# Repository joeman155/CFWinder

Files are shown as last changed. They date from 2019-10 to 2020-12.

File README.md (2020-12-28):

# CFWinder
** This is my gift to others to help them. I am still available - for paid Professional Engineering advice, 
   if your endeavour is for Financial gain. Otherwise, kindly refer to me somewhere in your notes, if you are blogging **

!!! Wishing you the very besy of success in your proejct. !!!

** WARNING **
Unfortunately there are no instructions for getting this up and running....but can give a quick overview...to get you started.

** The software and hardware required **
This project used LinuxCNC to control stepper motors. This is just a specialised version of Linux
with LinuxCNC installed...that does all the HARD work of controlling stepper motors. You still need to 
do some hard work, just not as much.  (Who wants to re-invent the wheel?)

Go get some good Stepper motors from OMC.  https://www.omc-stepperonline.com/  ... good PSU..... well spec'd Drivers...
and follow already well described tutorials on hooking these up.

NOTE: With LinuxCNC I used an oldish PC with an old style Parallel Port. IT works REALLY well!

** Folders in this code **
NOTE: There are three branches. master...for tubes..... to for noseccones.....use the NG variant for NOSECones.

> linucnc folder - has some configurations for the setup I had....PURELY LinuxCNC
    just some configurations
	
> gcodeGenerator - PHP web application that you installed on the SAME machine as linuxcnc with Apache + PHP. 
    You go to a web page...enter in some values...and it generates the GCode to do the job.
    A lot of patience and time required to figure this out...but less time than it would be to start from scratch.  
	Alternatively, start your own app... and pull out bits you like from here...
	
> 3-D_Designs
    A collection of unverified designs of parts used in my project.
    Use them as a starting point if you wish.

** Key Design **
- Three Axis - absolutely necessary   (Axle, left-right and tilt of CF)
- Go for L-XXX belts (don't try XL, even though it theoretically should)
- Have a heavy sturdy, flat bench
- Vibrations are your enemy
- The idler needs to be very well designed - using bearings. Has to be well balanced
- Get your gears professionaly drilled on a lathe.  (Unbalanced parts are your enemy).
- 8020.net is a good place to get the elements of your design.
- With your Mandrel, Aluminum worked out the best...but you NEED TO PREPARE IT VERY CAREFULLY. It takes a LOT OF TIME...Painful, but it pays off.
  It needs to be VERY VERY smooth....and a suitable former (not too tight!!!! needs to be put on to Mandrel)
  Yes....you will need dry-Ice to remove it....
  YEs.... ask someone to help remove the CF tube....
  Yes.... you shouldn't wait any longer than necessary before removing CF tube...it shrinks and you need to reduce all risks of not being able to remove it.
  
Unfortunately there is a lot that needs to be learnt on the job. But don't be put off. It is incredibly rewarding.

Joe

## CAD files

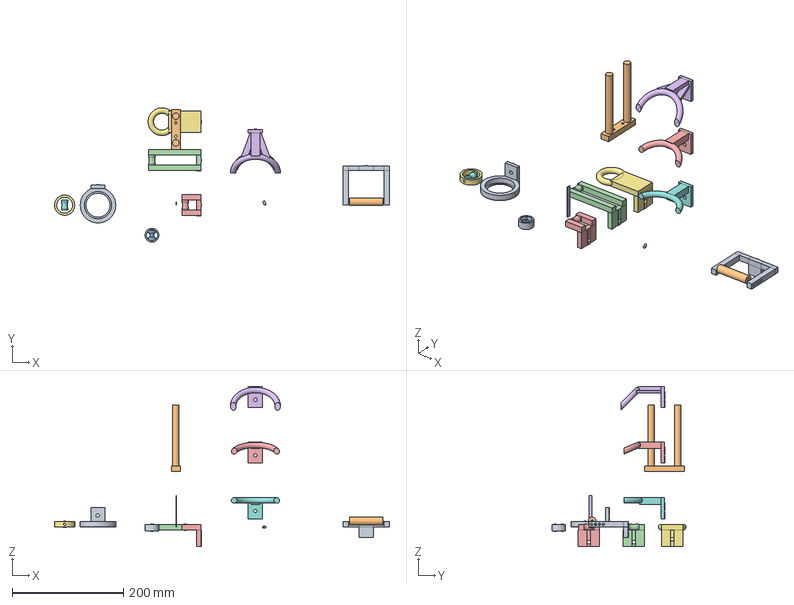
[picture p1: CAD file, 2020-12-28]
3-D_Designs/CFGuides.FCStd
602.2 x 241.5 x 288.0 mm
MidWayEyelet
Roller1
LEFT_RIGHT_GUIDE

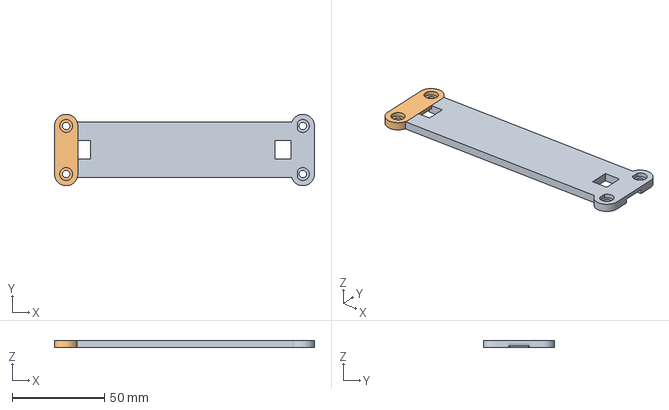
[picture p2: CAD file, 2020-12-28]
3-D_Designs/Balancer.FCStd
140.6 x 38.6 x 4.00 mm
ExtendedClamp
beltClamp

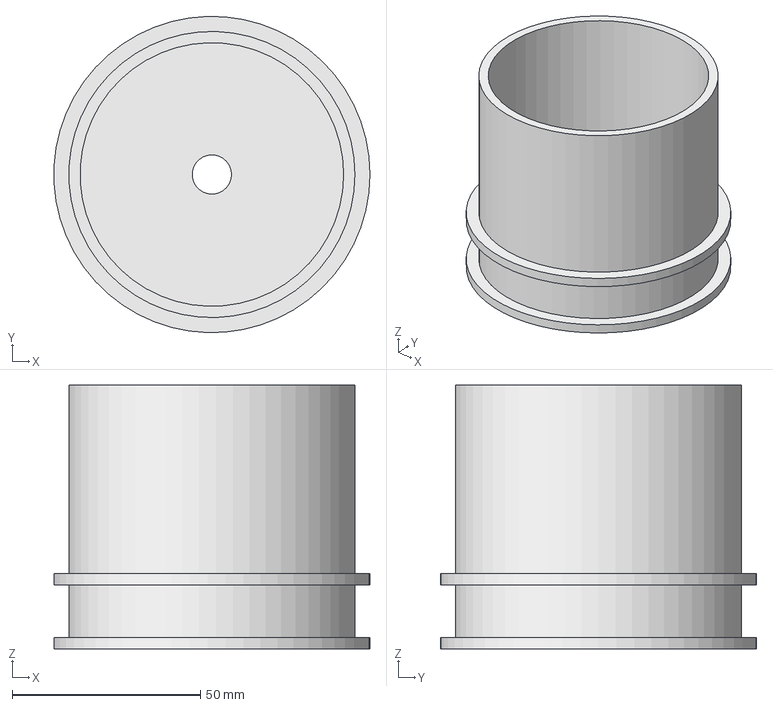
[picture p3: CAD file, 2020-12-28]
3-D_Designs/CarbonFiberRollHolder.FCStd
83.9 x 84.0 x 70.0 mm

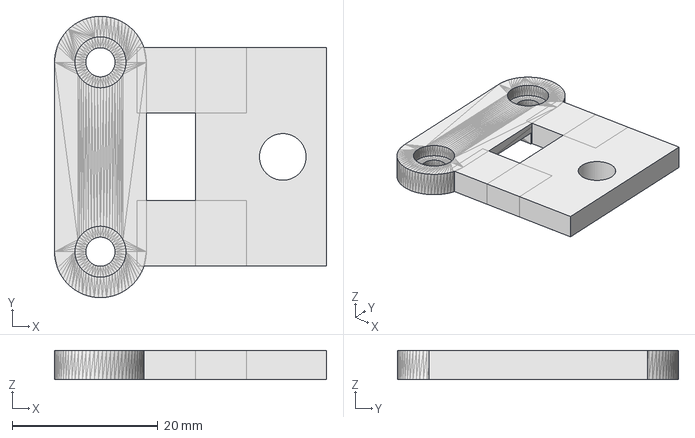
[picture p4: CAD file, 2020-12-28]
3-D_Designs/TopClampPart.FCStd
37.3 x 38.6 x 4.00 mm

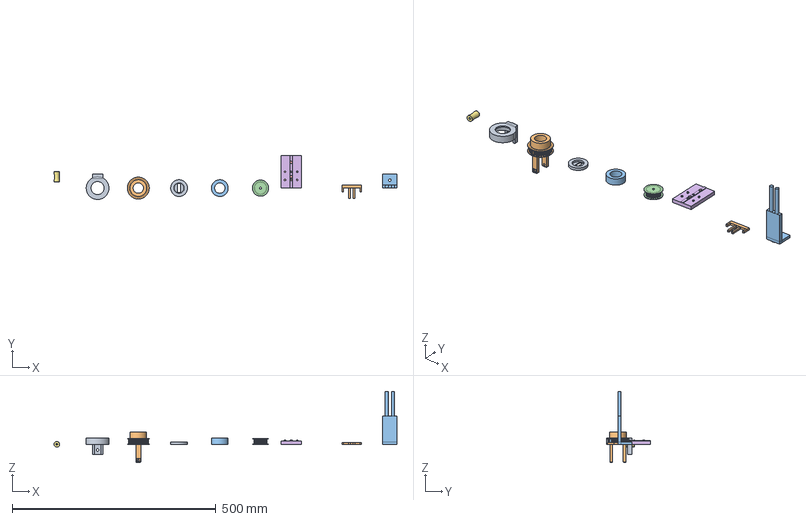
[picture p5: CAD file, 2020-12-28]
3-D_Designs/ThirdAxis.FCStd
842.0 x 108.0 x 175.0 mm
CF_Front_Dispenser

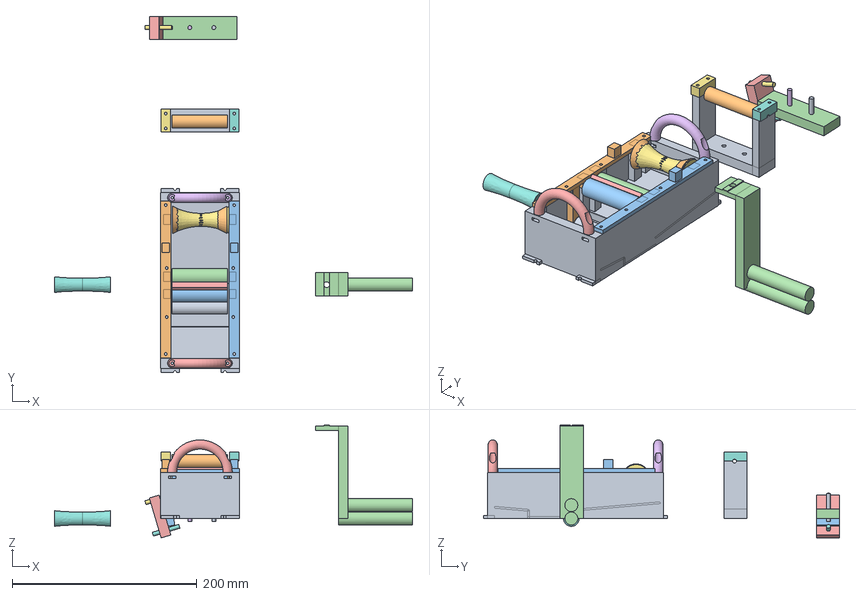
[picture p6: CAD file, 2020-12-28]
3-D_Designs/Epoxy_Tray.FCStd
387.5 x 385.0 x 122.0 mm
Roller1
ROLLER4
Roller2
Roller013
DRBlade
GlueRoller
CurvedEntryRoller
Roller011
FrontHardLimit
BackHardLimit
Roller015
BASE001
Pillar_Front_Right009
BASE
boltHole036
boltHole038
boltHole037
boltHole035

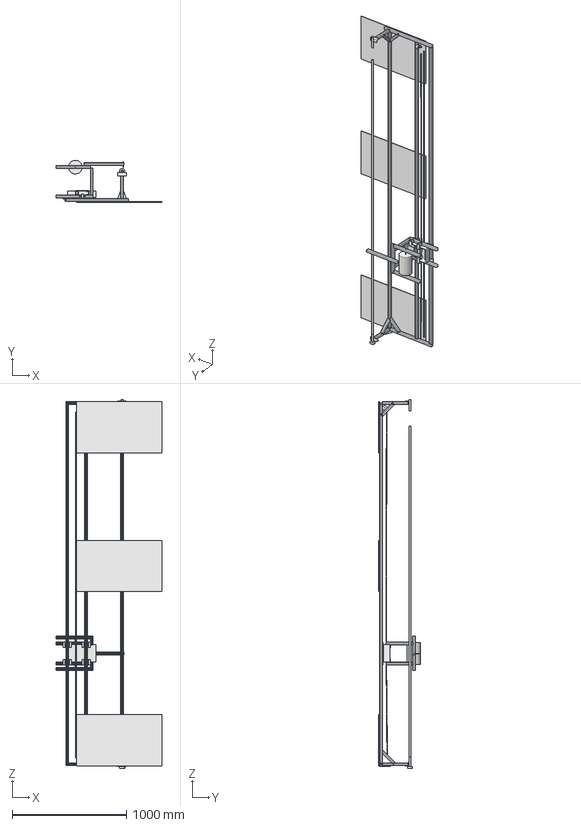
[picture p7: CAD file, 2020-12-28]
3-D_Designs/Starting_Idea_Inspiration.FCStd
926.6 x 370.6 x 3232.0 mm
longbeam001
longbeam002
depth001
depth002
longbeam003
fortyfive001
fortyfive002
Post001
DriveSpindle
fortyfive005
LinearDrivePulley002
Pillow_Bearing_Mount001
Post002
DrivenSpindle
fortyfive006
Pillow_Bearing_Mount002
GludeContainer
RW
LW
Epoxy_Tray_Riser001
Epoxy_Tray_Riser003
Epoxy_Tray_Riser005
Epoxy_Tray_Riser007
Special_Roller
BottomRoller
FrontTopRoller
BackTopRoller
CFGuide_HBeam002
Eyelet
LinearBearing001
LinearBearing002
LinearBearing003
LinearBearing004
Platform001
Belt001
Belt002
tray_Riser001
tray_Riser002
CF_Spindle_mount_base001
CF_Mount_Post001
CFGuidePost001
CFGuidePost002
CF_Mount_Post002
Belt003
IdlerPulley001
IdlerAxle
MotorAxle003
LinearDrivePulley004
LeftTableTop
RightTableTop001
LeftTableTop001
cf_Roll
Bobbin_Spindle
Smallmandrel

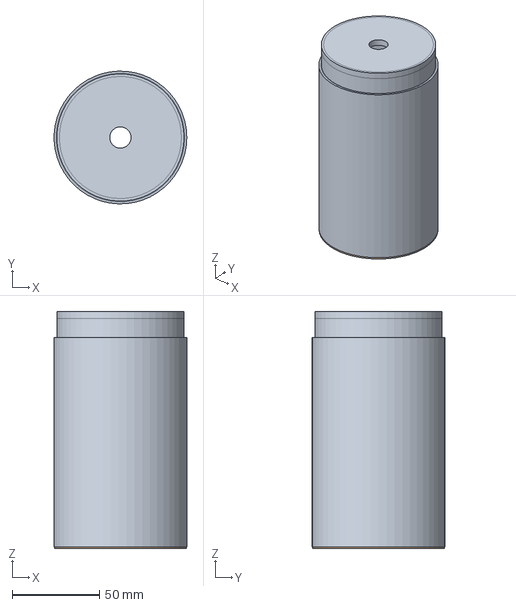
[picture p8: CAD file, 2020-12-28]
3-D_Designs/NoseCone_Mandrel.FCStd
76.1 x 76.2 x 136.0 mm
Core_part
Cap

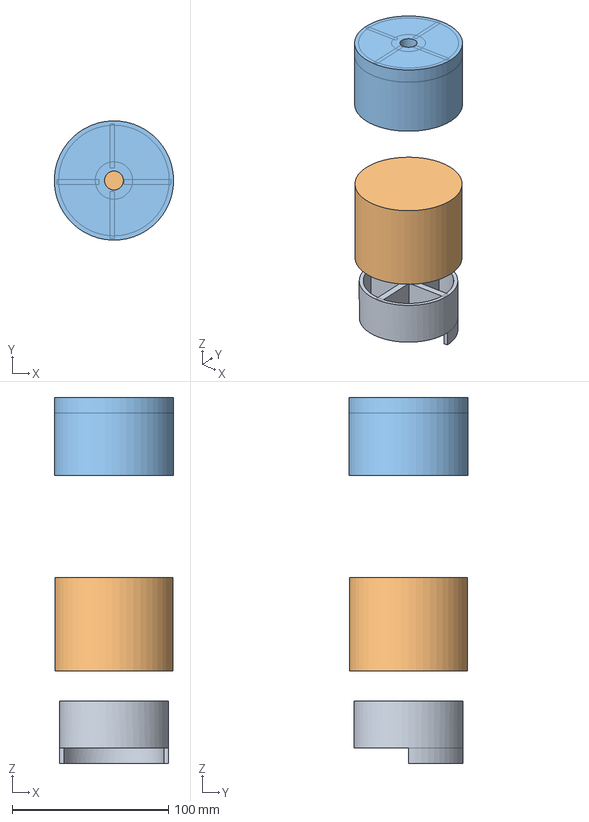
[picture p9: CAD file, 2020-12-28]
3-D_Designs/Mandrel_Shaft_Connect-for-CF-Tube.FCStd
76.2 x 76.3 x 234.0 mm
Mandrel_INSERT
Plastic_Mandrel
CF_Adapter_for_AF

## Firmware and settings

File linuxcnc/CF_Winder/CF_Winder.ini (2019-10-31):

# Generated by stepconf 1.1 at Mon Feb 25 21:22:01 2019
# If you make changes to this file, they will be
# overwritten when you run stepconf again

[EMC]
MACHINE = CF_Winder
DEBUG = 0

[DISPLAY]
DISPLAY = axis
EDITOR = gedit
POSITION_OFFSET = RELATIVE
POSITION_FEEDBACK = ACTUAL
ARCDIVISION = 64
GRIDS = 10mm 20mm 50mm 100mm 1in 2in 5in 10in
MAX_FEED_OVERRIDE = 1.2
MIN_SPINDLE_OVERRIDE = 0.5
MAX_SPINDLE_OVERRIDE = 1.2
DEFAULT_LINEAR_VELOCITY = 40.00
MIN_LINEAR_VELOCITY = 0
MAX_LINEAR_VELOCITY = 360.00
DEFAULT_ANGULAR_VELOCITY = 36.00
MIN_ANGULAR_VELOCITY = 0
MAX_ANGULAR_VELOCITY = 360.00
INTRO_GRAPHIC = linuxcnc.gif
INTRO_TIME = 5
PROGRAM_PREFIX = /home/user/linuxcnc/nc_files
INCREMENTS = 5mm 1mm .5mm .1mm .05mm .01mm .005mm
TOLERANCE_MM = 0.1

[FILTER]
PROGRAM_EXTENSION = .png,.gif,.jpg Greyscale Depth Image
PROGRAM_EXTENSION = .py Python Script
png = image-to-gcode
gif = image-to-gcode
jpg = image-to-gcode
py = python

[TASK]
TASK = milltask
CYCLE_TIME = 0.010

[RS274NGC]
PARAMETER_FILE = linuxcnc.var

[EMCMOT]
EMCMOT = motmod
COMM_TIMEOUT = 1.0
COMM_WAIT = 0.010
BASE_PERIOD = 100000
# BASE_PERIOD = 45028
SERVO_PERIOD = 1000000

[HAL]
HALFILE = CF_Winder.hal
HALFILE = custom.hal
POSTGUI_HALFILE = custom_postgui.hal

[TRAJ]
AXES = 4
COORDINATES = X Y Z A
LINEAR_UNITS = mm
ANGULAR_UNITS = degree
CYCLE_TIME = 0.010
DEFAULT_VELOCITY = 36.00
MAX_VELOCITY = 200.00

[EMCIO]
EMCIO = io
CYCLE_TIME = 0.100
TOOL_TABLE = tool.tbl

[AXIS_0]
TYPE = LINEAR
HOME = 0.0
MAX_VELOCITY = 200.0
MAX_ACCELERATION = 1200.0
STEPGEN_MAXACCEL = 1800.0
SCALE = 13.17
# SCALE Steps per unit
# microstep = 8
# steps per degree = 1.8
# 360 degrees per rev
# Outer Diameter = 36.5, So Pitch Diameter is about 37mm. So ...
# 1 revolution = circumference = 3.1415 *37 = 116.24
# 1 rev = 20 teeth - each tooth = 0.2" = 5.08" i.e. 1 rev = 116.24mm
# SCALE = (8/1.8) * (360/1) * (1/101.6) = 13.76
FERROR = 1
MIN_FERROR = .0025
MIN_LIMIT = -0.001
MAX_LIMIT = 2650.0
HOME_OFFSET = -10.000000
HOME_SEARCH_VEL = 35.00000
HOME_LATCH_VEL = -3.00000
HOME_IGNORE_LIMITS = YES
# HOME_SEARCH_VEL = 0
# HOME_LATCH_VEL = 0

[AXIS_1]
TYPE = ANGULAR
HOME = 0.0
MAX_VELOCITY = 200.0
MAX_ACCELERATION = 1000.0
STEPGEN_MAXACCEL = 1300
# SCALE = 3.96946564885
# SCALE = 5.77778
# SCALE = 5.78563
# SCALE = 5.779594
# SCALE = 5.87617
# SCALE = 5.8516
#
# I ended up realizing the fudge factors were wrong.
# Slowed the speed right down...and 5.78 is pretty close to it.
# SCALE = 5.78
# SCALE = 8.68877386155 # The theoretically correct value
# SCALE = 8.69
# SCALE = 8.7614
# THEN MULTIPLE by 0.99958227
# SCALE = 8.75774
# That meant it was short in the 4th test!!
# SCALE = 8.7614
# increasing microsteps to 32
# SCALE = 35.0456
# SCALE = 35.0456
# SCALE = 34.995
# SCALE = 35.0461754
# Times by 0.9998604
# SCALE = 35.0414806
# Times 0.99997016
# SCALE = 35.040435
# Times by 0.99997016 again
# SCALE = 35.0393894
# Times by 0.99069332
# SCALE = 34.71328903
# Times by 1.001480608
#SCALE = 34.7646858

# DECIDED TO REDUCE to 16 micro steps (from 32)
SCALE = 17.38


# SCALE Steps per degree
# microstep = 8
# steps per degree = 1.8
# Gear scale = 26/20 = 13/10 = 1.3
# 1 degree ....of travel for 38.1mm radius...= tangential distance of 0.66497044501mm
# (3.1415/180) * 38.1 = 0.66497044501mm
# Multipler = 1.00835459   # Experimentally found to ensure 360 degrees
#
# SCALE = (8/1.8) * (26/20) * (180 /(3.141592*38.1)) * 1.00835459= 8.7614
FERROR = 1
MIN_FERROR = .25
MIN_LIMIT = -999999999
MAX_LIMIT = 999999999
HOME_OFFSET = 0.0
HOME_SEARCH_VEL = 0
HOME_LATCH_VEL = 0

[AXIS_2]
TYPE = ANGULAR
HOME = 0.0
STEPGEN_MAXACCEL = 1300
MAX_VELOCITY = 200.0
MAX_ACCELERATION = 750.0
STEPGEN_MAXACCEL = 937.5
# SCALE = (32/1.8) * (30/20) = 26.67
# SCALE = 26.67
# SCALE = 29
SCALE = 28.03
FERROR = 1
MIN_FERROR = .25
MIN_LIMIT = -180.0
MAX_LIMIT = 180
HOME_OFFSET = 0.0
HOME_SEARCH_VEL = 0
HOME_LATCH_VEL = 0

[AXIS_3]
TYPE = ANGULAR
HOME = 0.0
MAX_VELOCITY = 1 
MAX_ACCELERATION = 20 
STEPGEN_MAXACCEL = 26
STEPGEN_MAXVEL = 2.6
SCALE = 2064
#
# I did test at 6 RPM (not fast) for 60 seconds. i.e. 10 secs per ref
# I expected it to finish where it started....for the theoretical value 
# of 2080 it did not...it overshot by about 11mm. So I determined that we needed
# closer to 2064 steps to ensure that it would not overshoot, This was about
# right.
#

# SCALE Steps per rev
# microstep = 8
# steps per degree = 1.8
# 360 degrees per rev
# 1 rev = 20 teeth - each tooth = 0.2" = 5.08" i.e. 1 rev = 101.6mm
# Gear scale = 26/20 = 13/10 = 1.3
# SCALE = (8/1.8) * (360/1) * (26/20) = 2080

FERROR = 25
MIN_FERROR = 1
MIN_LIMIT = -9999.0
MAX_LIMIT = 9999.0
HOME_OFFSET = 0.0
HOME_SEARCH_VEL = 0
HOME_LATCH_VEL = 0

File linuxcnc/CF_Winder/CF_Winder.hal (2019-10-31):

# Generated by stepconf 1.1 at Mon Feb 25 21:22:01 2019
# If you make changes to this file, they will be
# overwritten when you run stepconf again
loadrt trivkins
loadrt [EMCMOT]EMCMOT base_period_nsec=[EMCMOT]BASE_PERIOD servo_period_nsec=[EMCMOT]SERVO_PERIOD num_joints=[TRAJ]AXES
loadrt hal_parport cfg="0 out"
setp parport.0.reset-time 5000
loadrt stepgen step_type=0,0,0,0 ctrl_type=p,p,p,v
loadrt scale
loadrt orient
loadrt pid names=orient-pid

addf scale.0 servo-thread
setp scale.0.gain 0.0166667
addf parport.0.read base-thread
addf stepgen.make-pulses base-thread
addf parport.0.write base-thread
addf parport.0.reset base-thread

addf stepgen.capture-position servo-thread
addf motion-command-handler servo-thread
addf motion-controller servo-thread
addf stepgen.update-freq servo-thread
net spindle-cmd-rpm <= motion.spindle-speed-out => scale.0.in
net spindle-cmd-rpm-abs <= motion.spindle-speed-out-abs
net spindle-at-speed    => motion.spindle-at-speed


net estop-out       => parport.0.pin-01-out
net xstep           => parport.0.pin-02-out
setp parport.0.pin-02-out-reset 1
setp parport.0.pin-03-out-invert 1
net xdir            => parport.0.pin-03-out
net ystep           => parport.0.pin-04-out
net ydir            => parport.0.pin-05-out
net zstep           => parport.0.pin-06-out
net zdir            => parport.0.pin-07-out
net xenable         => parport.0.pin-14-out
net home-x          <= parport.0.pin-15-in
net min-home-x          <= parport.0.pin-15-in-not
net max-x           <= parport.0.pin-11-in-not


setp stepgen.0.position-scale [AXIS_0]SCALE
setp stepgen.0.steplen 1
setp stepgen.0.stepspace 0
setp stepgen.0.dirhold 33509
setp stepgen.0.dirsetup 33509
setp stepgen.0.maxaccel [AXIS_0]STEPGEN_MAXACCEL
net xpos-cmd axis.0.motor-pos-cmd => stepgen.0.position-cmd
net xpos-fb stepgen.0.position-fb => axis.0.motor-pos-fb
net xstep <= stepgen.0.step
net xdir <= stepgen.0.dir 
net xenable axis.0.amp-enable-out => stepgen.0.enable
net home-x => axis.0.home-sw-in
net max-x => axis.0.pos-lim-sw-in
net min-home-x => axis.0.neg-lim-sw-in


setp stepgen.1.position-scale [AXIS_1]SCALE
setp stepgen.1.steplen 1
setp stepgen.1.stepspace 0
setp stepgen.1.dirhold 33509
setp stepgen.1.dirsetup 33509
setp stepgen.1.maxaccel [AXIS_1]STEPGEN_MAXACCEL
setp stepgen.1.maxvel [AXIS_1]MAX_VELOCITY
net ypos-cmd axis.1.motor-pos-cmd => stepgen.1.position-cmd
net ypos-fb stepgen.1.position-fb => axis.1.motor-pos-fb
net ystep <= stepgen.1.step
net ydir <= stepgen.1.dir
net yenable axis.1.amp-enable-out => stepgen.1.enable


setp stepgen.2.position-scale [AXIS_2]SCALE
setp stepgen.2.steplen 1
setp stepgen.2.stepspace 0
setp stepgen.2.dirhold 33509
setp stepgen.2.dirsetup 33509
setp stepgen.2.maxaccel [AXIS_2]STEPGEN_MAXACCEL
net zpos-cmd axis.2.motor-pos-cmd => stepgen.2.position-cmd
net zpos-fb stepgen.2.position-fb => axis.2.motor-pos-fb
net zstep <= stepgen.2.step
net zdir <= stepgen.2.dir
net zenable axis.2.amp-enable-out => stepgen.2.enable

setp stepgen.3.position-scale [AXIS_3]SCALE
setp stepgen.3.steplen 1
setp stepgen.3.stepspace 0
setp stepgen.3.dirhold 33509
setp stepgen.3.dirsetup 33509
setp stepgen.3.maxaccel [AXIS_3]STEPGEN_MAXACCEL
setp stepgen.3.maxvel [AXIS_3]MAX_VELOCITY
# net spindle-cmd-rps <= scale.0.out => stepgen.3.velocity-cmd
# net ystep <= stepgen.3.step
# net ydir <= stepgen.3.dir
# net spindle-on motion.spindle-on => stepgen.3.enable

net estop-out <= iocontrol.0.user-enable-out
net estop-out => iocontrol.0.emc-enable-in

loadusr -W hal_manualtoolchange
net tool-change iocontrol.0.tool-change => hal_manualtoolchange.change
net tool-changed iocontrol.0.tool-changed <= hal_manualtoolchange.changed
net tool-number iocontrol.0.tool-prep-number => hal_manualtoolchange.number
net tool-prepare-loopback iocontrol.0.tool-prepare => iocontrol.0.tool-prepared

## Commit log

2019-03-12 * Starting to add project files.
    [CF_Winder.hal, CF_Winder.ini, custom.hal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]
2019-03-15 * Re org CF_Winder dir * Removing some unrequired parameters from Gcode generator * Moving away from _y to _s (s for spindle) * Fixed up calcs for second transition - was setting wrong Center points.
    [CF_Winder.hal, CF_Winder.ini, custom.hal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]
2019-03-17 * Updated linuxcnc config to allow use of Y axis with mm. * Updating gcode generator code to allow creation of files with curved transitions.
    [CF_Winder.ini]
2019-03-17 * SPindle direction control * Show feedrates now.
2019-03-18 * Fine tuning Y-Axis scale
    [CF_Winder.ini]
2019-03-27 * Coded so not rely upon user entering in a length of tube to make. Instead, user enters # of degrees for the "usable" section of the tube (not transitions) * Coding to allow placement of CF dispense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
2019-04-16 * Adding in Z-Axis
2019-04-16 * Added Z-Axis
    [CF_Winder.hal, CF_Winder.ini]
2019-04-23 * Added z-axis motion.
2019-04-28 * Mods to automate transitions and mods to ensure z-axis is moved to correct angle.
2019-04-29 * Other fixes to get correct z axis angle when doing straight run * Showing extra turn on the process page.
2019-04-30 * Added fudge factor for z-axis * Using z_angle instead of z_travel
2019-05-04 * Added offset of useful length of tube to output.
2019-06-22 * Added Tube Load Software.
2019-07-19 * added code for heat gun.
2019-10-25 * Removed hard coding of where to end heat-gun.
2019-10-31 * Modified Winder to work with 3-D printed gear on resin bath stepper motor.
    [CF_Winder.hal, CF_Winder.ini]
2020-12-28 * Added 3-D designs (freecad)
    [Balancer.FCStd, CFGuides.FCStd, CarbonFiberRollHolder.FCStd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]
